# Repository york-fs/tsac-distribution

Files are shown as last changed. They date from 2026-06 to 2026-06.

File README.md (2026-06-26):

# TSAC Distribution Board







The TSAC distribution board is the interface between the PCBs inside the TSAC and the rest of the LVS. It connects to
the rear distribution via a 23-pin AMPSEAL connector and connects primarily to the BMS, IMD, and precharge PCB inside of
the TSAC. It also provides split termination for the CAN bus.

[Latest Release](https://github.com/york-fs/tsac-distribution/releases/latest)
[Interactive BOM](https://york-fs.github.io/tsac-distribution/ibom.html)

Render Preview

## Cloning

A recursive clone must be used to download the `kicad-library` repository:

    git clone --recursive https://github.com/york-fs/tsac-distribution.git

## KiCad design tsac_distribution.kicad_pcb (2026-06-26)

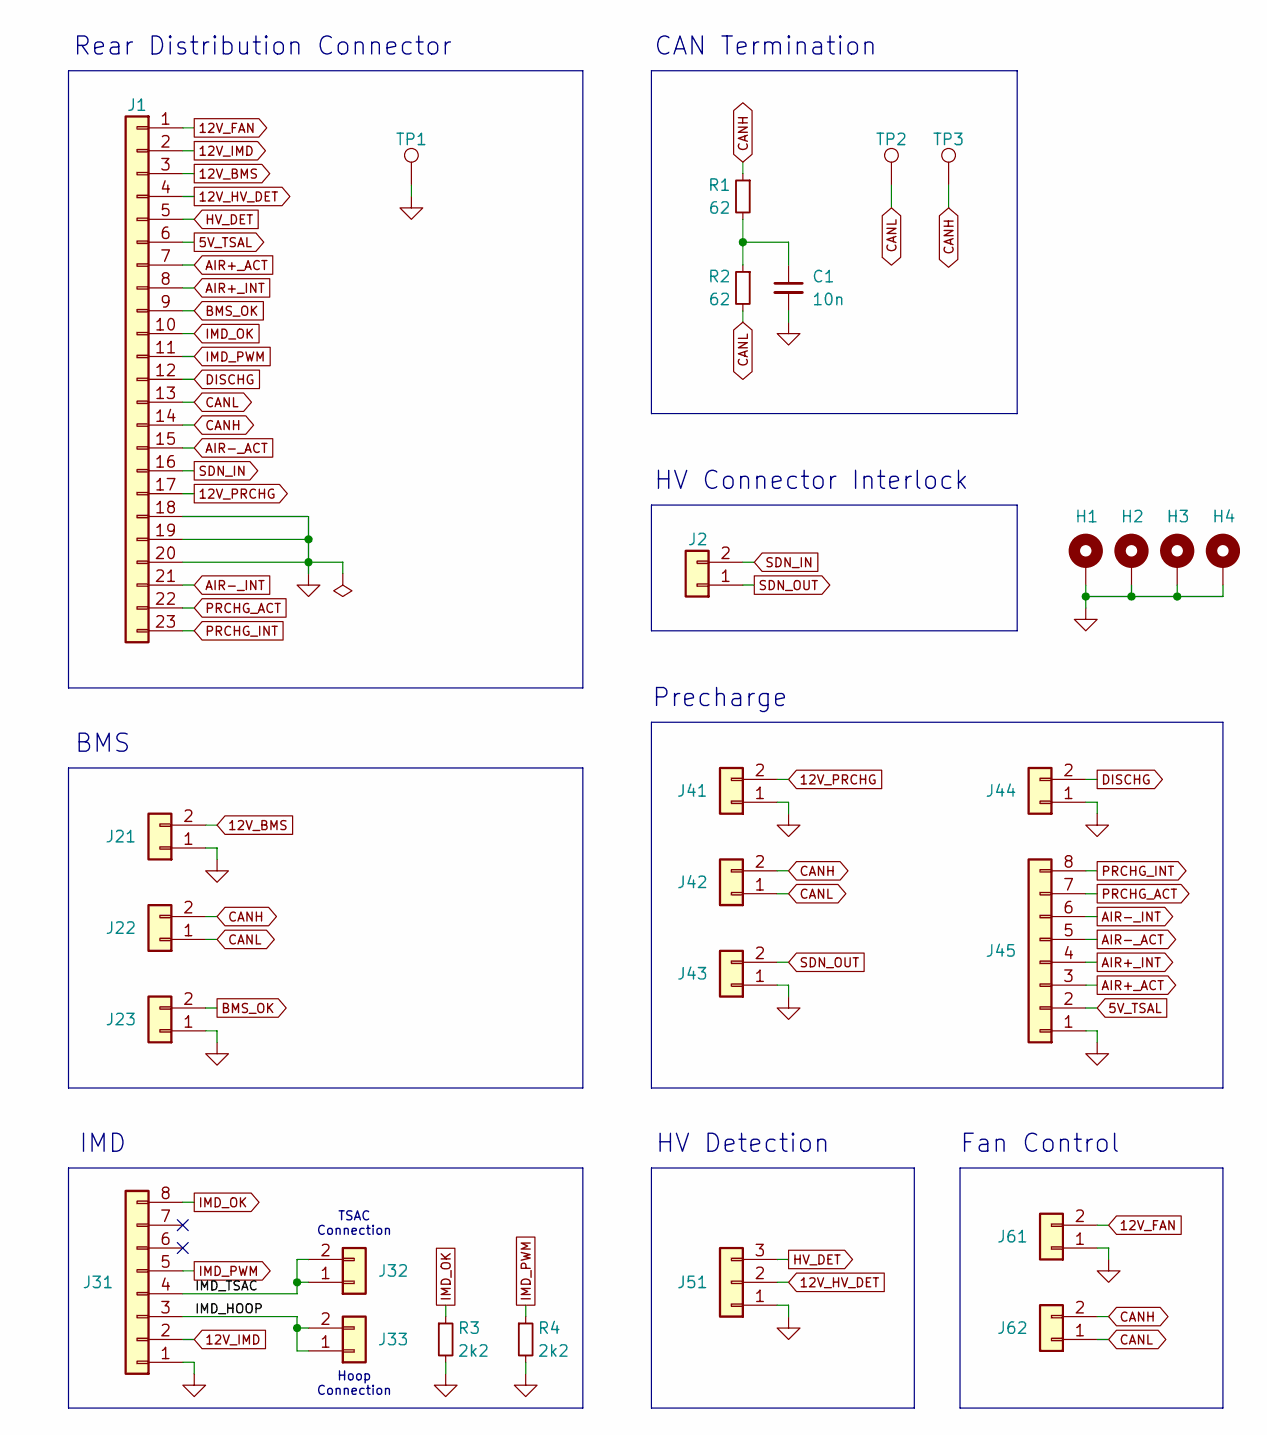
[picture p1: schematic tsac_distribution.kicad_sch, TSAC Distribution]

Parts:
C1: 10n; C_0603_1608Metric
H1, H2, H3, H4: MountingHole_Pad; MountingHole_3.2mm_M3_Pad_Via
J1: Conn_01x23; AMPSEAL-23-776087; Mfr # 776087-1; DigiKey # A107007-ND
J2, J43, J44: Conn_01x02; MolexMicrofitPlus1x2; Mfr # 2157601032; DigiKey # 900-2157601032-ND
J21, J41, J61: Conn_01x02; MolexMicrofitPlus1x2; Mfr # 2157601022; DigiKey # 900-2157601022-ND
J22, J23, J32, J33, J42, J62: Conn_01x02; MolexMicrofitPlus1x2; Mfr # 2157601002; DigiKey # 900-2157601002-ND
J31: Conn_01x08; MolexMicrofitPlus1x8; Mfr # 2-1445088-8; DigiKey # 2-1445088-8-ND
J45: Conn_01x08; MolexMicrofitPlus1x8; Mfr # 2157601008; DigiKey # 900-2157601008-ND
J51: Conn_01x03; MolexMicrofitPlus1x3; Mfr # 2157601003; DigiKey # 900-2157601003-ND
R1, R2: 62; R_1206_3216Metric; Mfr # CRCW120662R0JNEAHP; DigiKey # 541-62UACT-ND
R3, R4: 2k2; R_0603_1608Metric
TP1: TestPoint; TestPoint_Keystone_5019_Miniature; Mfr # 5019; DigiKey # 36-5019CT-ND
TP2, TP3: TestPoint; TestPoint_Keystone_5000-5004_Miniature

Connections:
5V_TSAL: J1.6, J45.2
12V_BMS: J1.3, J21.2
12V_FAN: J1.1, J61.2
12V_HV_DET: J1.4, J51.2
12V_IMD: J1.2, J31.2
12V_PRCHG: J1.17, J41.2
/IMD_HOOP: J31.3, J33.1, J33.2
/IMD_TSAC: J31.4, J32.1, J32.2
AIR+_ACT: J1.7, J45.3
AIR+_INT: J1.8, J45.4
AIR-_ACT: J1.15, J45.5
AIR-_INT: J1.21, J45.6
BMS_OK: J1.9, J23.2
CANH: J1.14, J22.2, J42.2, J62.2, R1.1, TP3.1
CANL: J1.13, J22.1, J42.1, J62.1, R2.2, TP2.1
DISCHG: J1.12, J44.2
GND: C1.2, H1.1, H2.1, H3.1, H4.1, J1.18, J1.19, J1.20, J21.1, J23.1, J31.1, J41.1, J43.1, J44.1, J45.1, J51.1, J61.1, R3.2, R4.2, TP1.1
HV_DET: J1.5, J51.3
IMD_OK: J1.10, J31.8, R3.1
IMD_PWM: J1.11, J31.5, R4.1
unnamed: C1.1, R1.2, R2.1
PRCHG_ACT: J1.22, J45.7
PRCHG_INT: J1.23, J45.8
SDN_IN: J1.16, J2.2
SDN_OUT: J2.1, J43.2

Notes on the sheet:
HV Connector Interlock
CAN Termination
Rear Distribution Connector
HV Detection
Fan Control
Precharge
BMS
Hoop Connection
IMD
TSAC Connection

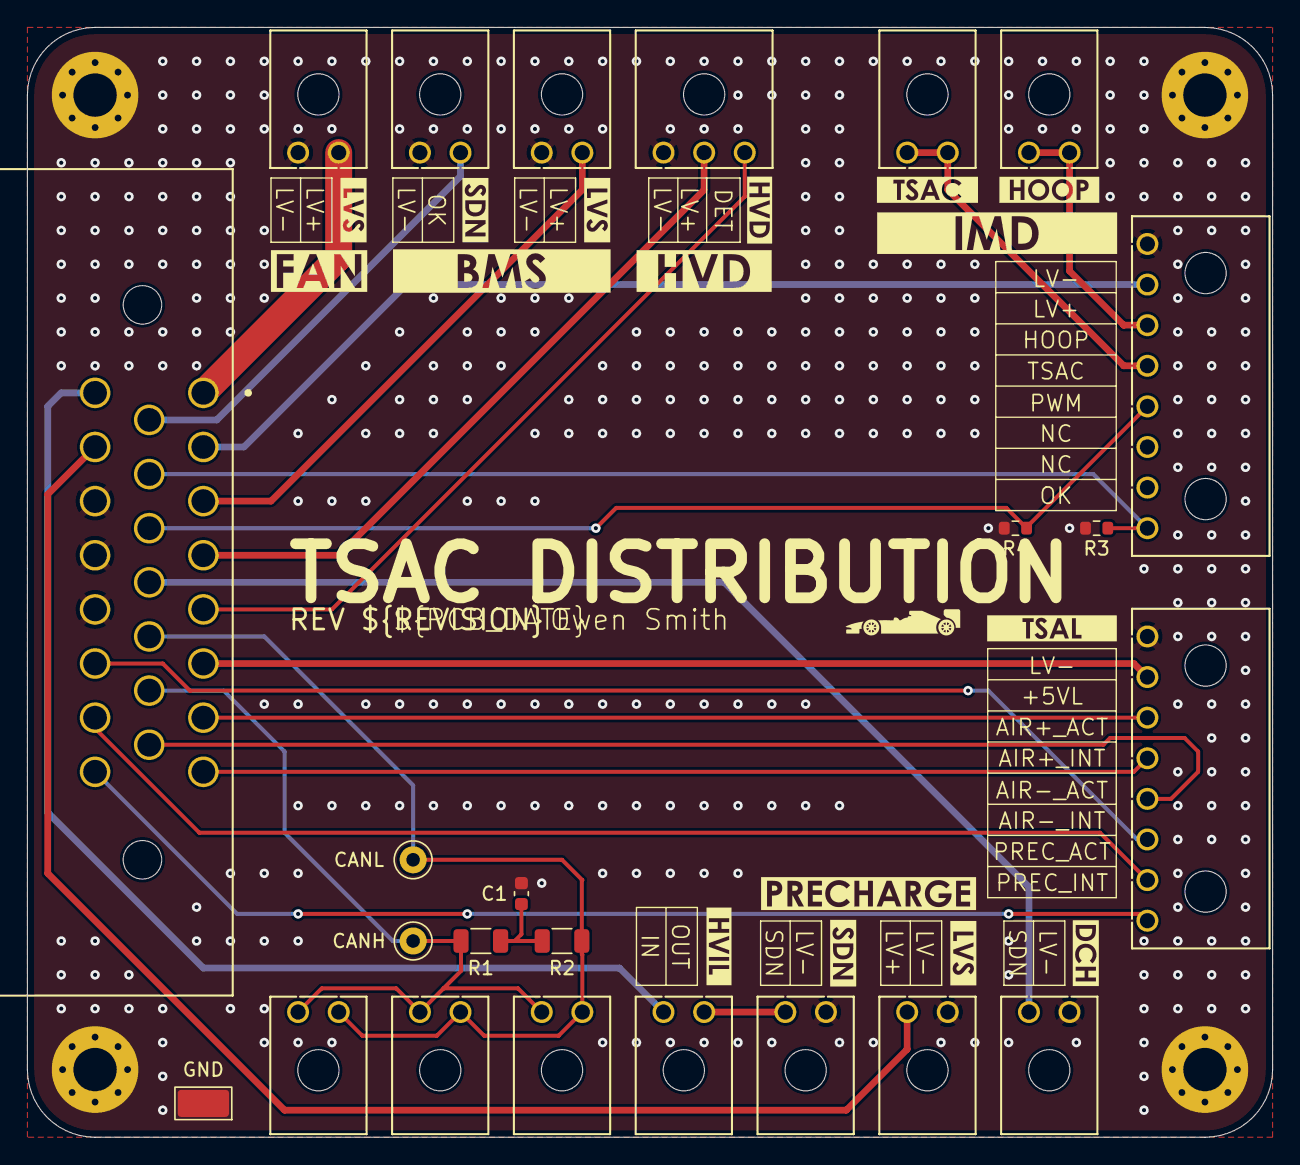
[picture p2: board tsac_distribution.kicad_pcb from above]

Board: 2 copper layers, 92.0 x 82.0 mm, 44 parts (0 on the bottom side), 25 nets.

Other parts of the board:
kibuzzard-6A07B746: G***; kibuzzard-6A07B746
kibuzzard-6A07B875: G***; kibuzzard-6A07B875
kibuzzard-6A07C1EF: G***; kibuzzard-6A07C1EF
kibuzzard-6A3540DA: G***; kibuzzard-6A3540DA
kibuzzard-6A3541C8: G***; kibuzzard-6A3541C8
kibuzzard-6A35413C: G***; kibuzzard-6A35413C
kibuzzard-6A35415C: G***; kibuzzard-6A35415C
kibuzzard-6A088056: G***; kibuzzard-6A088056
kibuzzard-6A354048: G***; kibuzzard-6A354048
kibuzzard-6A354054: G***; kibuzzard-6A354054
kibuzzard-6A354262: G***; kibuzzard-6A354262
kibuzzard-6A354707: G***; kibuzzard-6A354707
kibuzzard-6910B7D7, kibuzzard-6910B7D7#2, kibuzzard-6910B7D7#3: G***; kibuzzard-6910B7D7
kibuzzard-6940937D: G***; kibuzzard-6940937D

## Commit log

2026-06-19 *: Add layout
    [tsac_distribution.kicad_pcb, tsac_distribution.kicad_sch]
2026-06-19 pcb: Run track cleanup
    [tsac_distribution.kicad_pcb]
2026-06-23 pcb: Setup AISLER push
    [tsac_distribution.kicad_pcb]
2026-06-26 ci: Add KiCad CI
2026-06-26 pcb: Add models for Molex MF+ 1x8 connectors
    [tsac_distribution.kicad_pcb]
